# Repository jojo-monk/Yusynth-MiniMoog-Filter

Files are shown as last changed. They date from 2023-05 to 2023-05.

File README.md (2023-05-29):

# Yusynth-MiniMoog-Filter
Adaptation du Yusynth [MiniMoog Filter](http://yusynth.net/Modular/index_en.html) au format Eurorack

testé et fonctionnel.

petit défaut esthetique : sérigraphie un peu trop petite et trop proche des boutons.

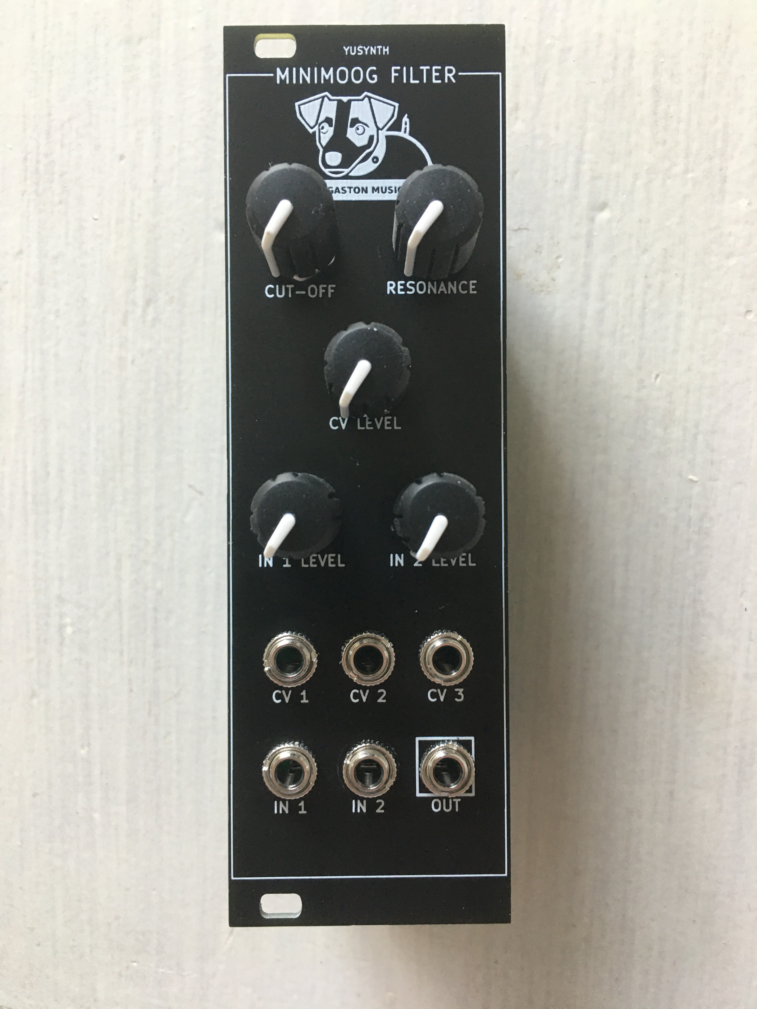
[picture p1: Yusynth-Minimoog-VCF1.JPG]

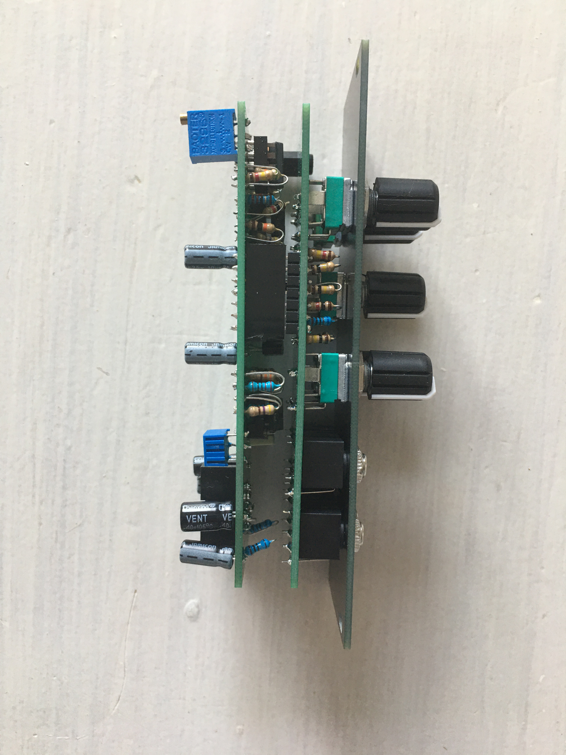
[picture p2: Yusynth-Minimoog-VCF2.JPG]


[Build document](https://htmlpreview.github.io/?https://github.com/jojo-monk/Yusynth-MiniMoog-Filter/blob/main/ibom.html)

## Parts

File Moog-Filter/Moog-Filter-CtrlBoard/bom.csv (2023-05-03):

Designator | Footprint | Quantity | Value | LCSC Part #
H1 | MountingHole_3.2mm_M3 | 1 | MountingHole
J3 | Jack_3.5mm_QingPu_WQP-PJ398SM_Vertical | 1 | IN1
J4 | Jack_3.5mm_QingPu_WQP-PJ398SM_Vertical | 1 | IN2
J5 | Jack_3.5mm_QingPu_WQP-PJ398SM_Vertical | 1 | CV1
J6 | Jack_3.5mm_QingPu_WQP-PJ398SM_Vertical | 1 | CV2
J7 | Jack_3.5mm_QingPu_WQP-PJ398SM_Vertical | 1 | CV3
J8 | PinHeader_1x07_P2.54mm_Vertical | 1 | Conn_01x07_Female
J9 | Jack_3.5mm_QingPu_WQP-PJ398SM_Vertical | 1 | OUT
R27 | R_Axial_DIN0207_L6.3mm_D2.5mm_P2.54mm_Vertical | 1 | 680
R28 | R_Axial_DIN0207_L6.3mm_D2.5mm_P2.54mm_Vertical | 1 | 150K
R29, R30, R32, R33 | R_Axial_DIN0207_L6.3mm_D2.5mm_P2.54mm_Vertical | 4 | 100K
R31 | R_Axial_DIN0207_L6.3mm_D2.5mm_P2.54mm_Vertical | 1 | 120K
R34 | R_Axial_DIN0207_L6.3mm_D2.5mm_P2.54mm_Vertical | 1 | 1K
RV4 | Potentiometer_Alpha_RD901F-40-00D_Single_Vertical | 1 | Freq 10K Lin
RV5, RV6 | Potentiometer_Alpha_RD901F-40-00D_Single_Vertical | 2 | INPUT LEVEL 50K Log
RV7 | Potentiometer_Alpha_RD901F-40-00D_Single_Vertical | 1 | Ctrl LEVEL 50K Lin
RV8 | Potentiometer_Alpha_RD901F-40-00D_Single_Vertical | 1 | Emphasis 50K antilog

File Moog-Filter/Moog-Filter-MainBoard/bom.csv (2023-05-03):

Designator | Footprint | Quantity | Value | LCSC Part #
C1 | C_Rect_L7.0mm_W3.5mm_P5.00mm | 1 | 100pF
C10, C11, C2 | CP_Radial_D5.0mm_P2.00mm | 3 | 10uF
C12 | C_Rect_L7.0mm_W3.5mm_P5.00mm | 1 | 100nF
C13, C14 | CP_Radial_D5.0mm_P2.00mm | 2 | 22uF
C3, C4, C5, C6 | C_Rect_L7.0mm_W3.5mm_P5.00mm | 4 | 47nF
C7 | CP_Radial_D8.0mm_P3.50mm | 1 | 220uF
C8, C9 | C_Rect_L7.0mm_W3.5mm_P5.00mm | 2 | 220nF
H2 | MountingHole_3.2mm_M3 | 1 | MountingHole
J1 | PinHeader_1x07_P2.54mm_Vertical | 1 | Conn_01x07_Male
J2 | Eurorack_power_header | 1 | EURO_PWR_2x5
Q1 | TO-92_HandSolder | 1 | BC557
Q2, Q3, Q4, Q5, Q6, Q7 | TO-92_HandSolder | 6 | BC547
R1, R23 | R_Axial_DIN0207_L6.3mm_D2.5mm_P2.54mm_Vertical | 2 | 56K
R10 | R_Axial_DIN0207_L6.3mm_D2.5mm_P2.54mm_Vertical | 1 | 100K
R11, R20, R21 | R_Axial_DIN0207_L6.3mm_D2.5mm_P2.54mm_Vertical | 3 | 1K
R12, R5, R6, R7 | R_Axial_DIN0207_L6.3mm_D2.5mm_P2.54mm_Vertical | 4 | 150
R13 | R_Axial_DIN0207_L6.3mm_D2.5mm_P2.54mm_Vertical | 1 | 220
R14, R4 | R_Axial_DIN0207_L6.3mm_D2.5mm_P2.54mm_Vertical | 2 | 330
R15, R16 | R_Axial_DIN0207_L6.3mm_D2.5mm_P2.54mm_Vertical | 2 | 47K
R17, R22 | R_Axial_DIN0207_L6.3mm_D2.5mm_P2.54mm_Vertical | 2 | 220K
R18 | R_Axial_DIN0207_L6.3mm_D2.5mm_P2.54mm_Vertical | 1 | 22
R19 | R_Axial_DIN0207_L6.3mm_D2.5mm_P2.54mm_Vertical | 1 | 180
R2 | R_Axial_DIN0207_L6.3mm_D2.5mm_P2.54mm_Vertical | 1 | 1.8K
R24 | R_Axial_DIN0207_L6.3mm_D2.5mm_P2.54mm_Vertical | 1 | 120K
R25, R26 | R_Axial_DIN0207_L6.3mm_D2.5mm_P2.54mm_Vertical | 2 | 10
R3 | R_Axial_DIN0207_L6.3mm_D2.5mm_P2.54mm_Vertical | 1 | 10K
R8, R9 | R_Axial_DIN0207_L6.3mm_D2.5mm_P2.54mm_Vertical | 2 | 470
RV1 | Potentiometer_Bourns_3296W_Vertical | 1 | 500
RV2 | Potentiometer_Bourns_3296W_Vertical | 1 | 10K
RV3 | Potentiometer_Bourns_3296W_Vertical | 1 | 1K
U1 | DIP-8_W7.62mm_LongPads | 1 | TL072
U2, U3 | DIP-14_W7.62mm_LongPads | 2 | CA3046

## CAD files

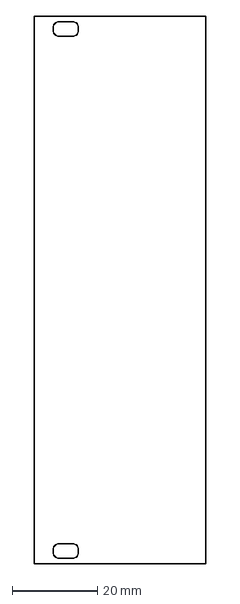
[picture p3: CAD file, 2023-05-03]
Moog-Filter/FrontPanel.dxf
40.3 x 128.4 mm

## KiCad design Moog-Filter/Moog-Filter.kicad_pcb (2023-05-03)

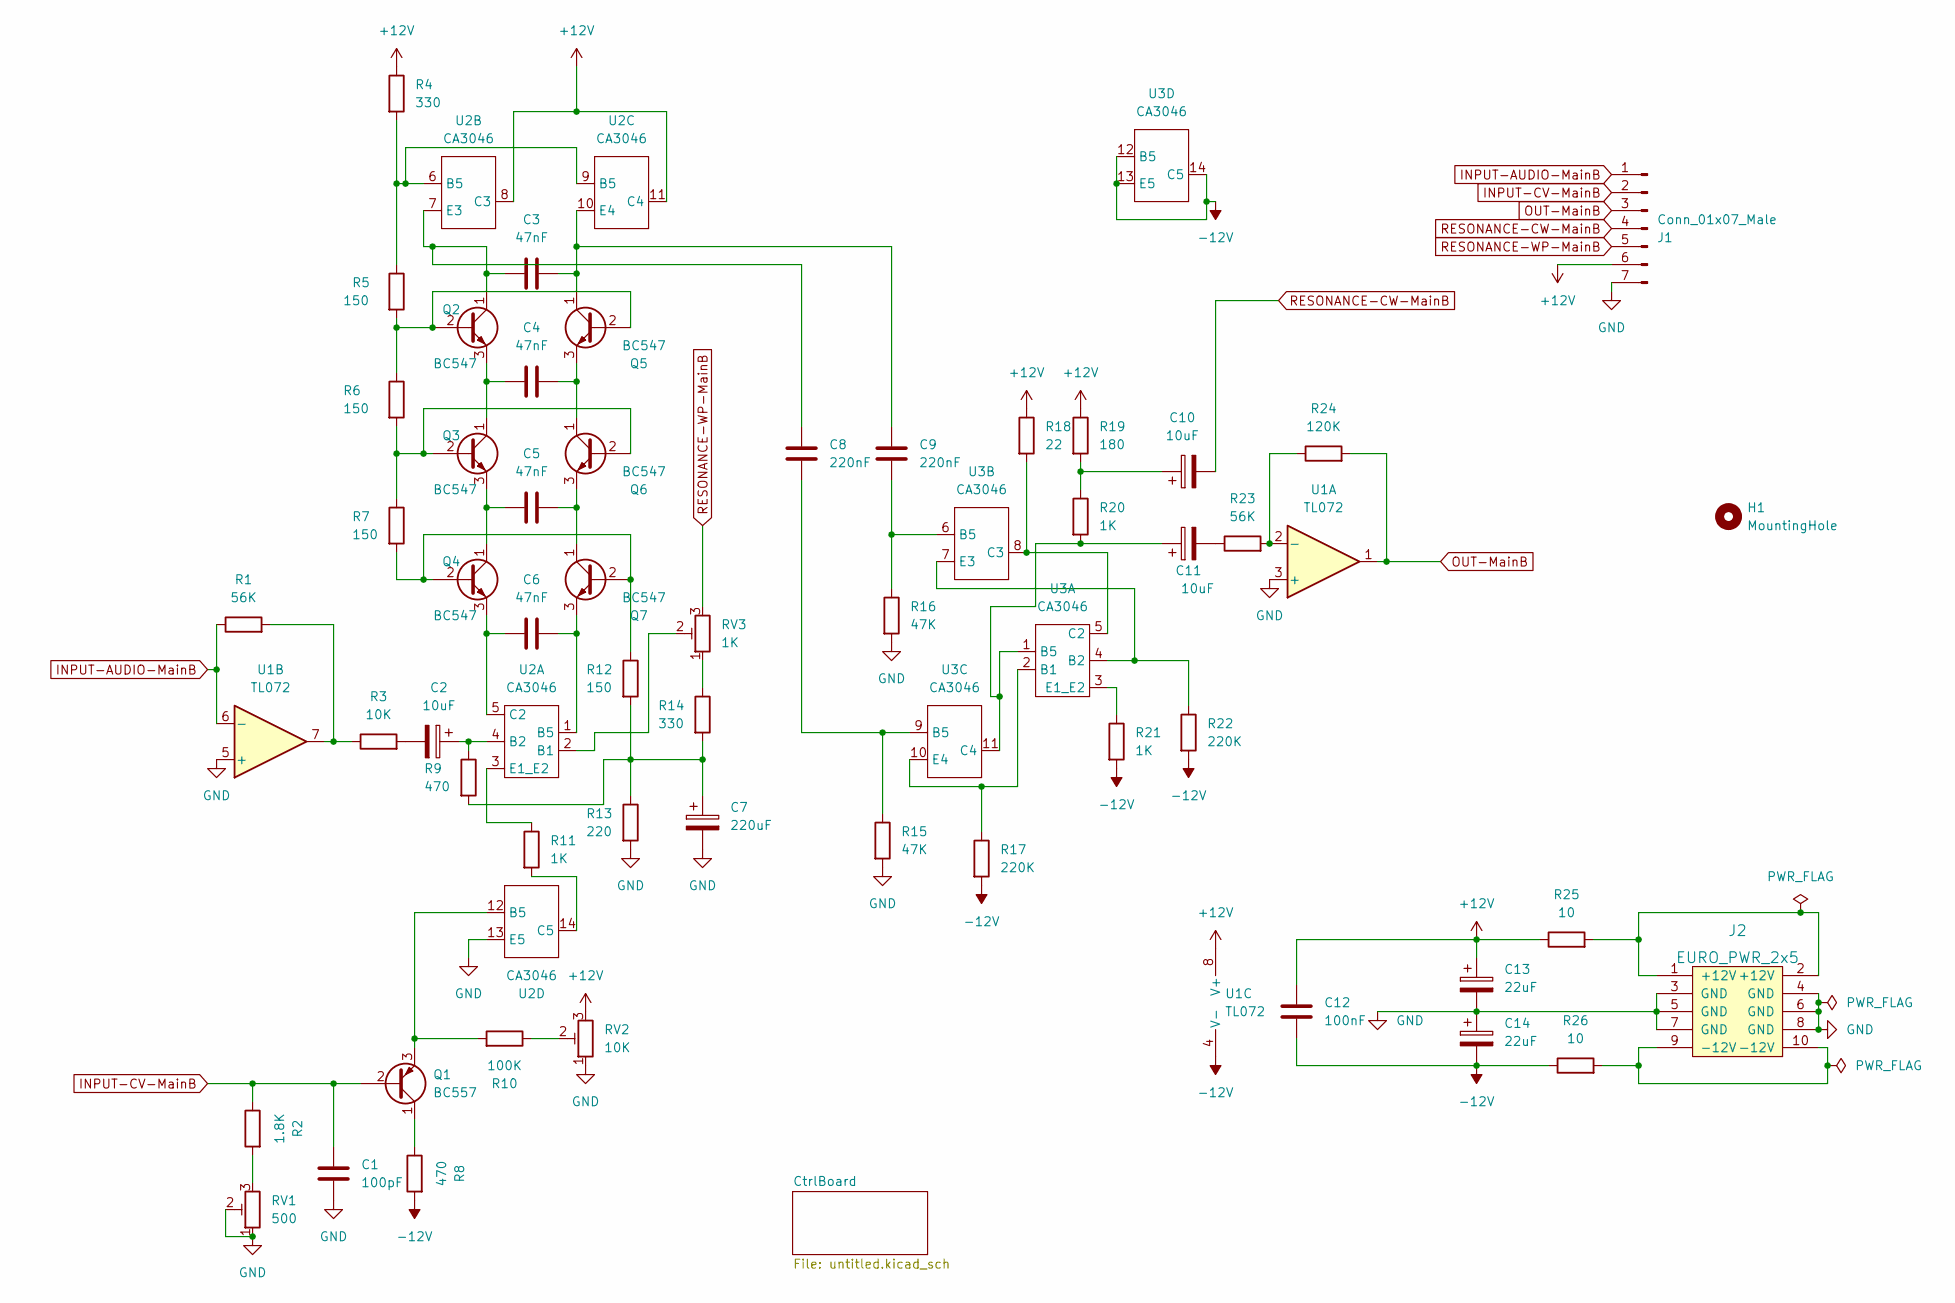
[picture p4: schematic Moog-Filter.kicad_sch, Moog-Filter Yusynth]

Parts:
C1: 100pF; C_Rect_L7.0mm_W3.5mm_P5.00mm
C2, C10, C11: 10uF; CP_Radial_D5.0mm_P2.00mm
C3, C4, C5, C6: 47nF; C_Rect_L7.0mm_W3.5mm_P5.00mm
C7: 220uF; CP_Radial_D8.0mm_P3.50mm
C8, C9: 220nF; C_Rect_L7.0mm_W3.5mm_P5.00mm
C12: 100nF; C_Rect_L7.0mm_W3.5mm_P5.00mm
C13, C14: 22uF; CP_Radial_D5.0mm_P2.00mm
H1: MountingHole; MountingHole_3.2mm_M3
J1: Conn_01x07_Male; PinHeader_1x07_P2.54mm_Vertical
J2: EURO_PWR_2x5; Eurorack_power_header
Q1: BC557; TO-92_HandSolder
Q2, Q3, Q4, Q5, Q6, Q7: BC547; TO-92_HandSolder
R1, R23: 56K; R_Axial_DIN0207_L6.3mm_D2.5mm_P2.54mm_Vertical
R2: 1.8K; R_Axial_DIN0207_L6.3mm_D2.5mm_P2.54mm_Vertical
R3: 10K; R_Axial_DIN0207_L6.3mm_D2.5mm_P2.54mm_Vertical
R4, R14: 330; R_Axial_DIN0207_L6.3mm_D2.5mm_P2.54mm_Vertical
R5, R6, R7, R12: 150; R_Axial_DIN0207_L6.3mm_D2.5mm_P2.54mm_Vertical
R8, R9: 470; R_Axial_DIN0207_L6.3mm_D2.5mm_P2.54mm_Vertical
R10: 100K; R_Axial_DIN0207_L6.3mm_D2.5mm_P2.54mm_Vertical
R11, R20, R21: 1K; R_Axial_DIN0207_L6.3mm_D2.5mm_P2.54mm_Vertical
R13: 220; R_Axial_DIN0207_L6.3mm_D2.5mm_P2.54mm_Vertical
R15, R16: 47K; R_Axial_DIN0207_L6.3mm_D2.5mm_P2.54mm_Vertical
R17, R22: 220K; R_Axial_DIN0207_L6.3mm_D2.5mm_P2.54mm_Vertical
R18: 22; R_Axial_DIN0207_L6.3mm_D2.5mm_P2.54mm_Vertical
R19: 180; R_Axial_DIN0207_L6.3mm_D2.5mm_P2.54mm_Vertical
R24: 120K; R_Axial_DIN0207_L6.3mm_D2.5mm_P2.54mm_Vertical
R25, R26: 10; R_Axial_DIN0207_L6.3mm_D2.5mm_P2.54mm_Vertical
RV1: 500; Potentiometer_Bourns_3296W_Vertical
RV2: 10K; Potentiometer_Bourns_3296W_Vertical
RV3: 1K; Potentiometer_Bourns_3296W_Vertical
U1: TL072; DIP-8_W7.62mm_LongPads
U2, U3: CA3046; DIP-14_W7.62mm_LongPads

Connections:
+12V: C12.1, C13.1, J1.6, R4.1, R18.1, R19.1, R25.1, RV2.3, U1.8 (V+), U2.8 (C3), U2.11 (C4); also elsewhere on the board
-12V: C12.2, C14.2, R8.2, R17.2, R21.2, R22.2, R26.1, U1.4 (V-), U3.12 (B5), U3.13 (E5), U3.14 (C5)
GND: C1.2, C7.2, C13.2, C14.1, J1.7, J2.3 (GND), J2.4 (GND), J2.5 (GND), J2.6 (GND), J2.7 (GND), J2.8 (GND), R13.2, R15.2, R16.2, RV1.1, RV1.2, RV2.1, U1.3 (+), U1.5 (+), U2.13 (E5); also elsewhere on the board
INPUT-AUDIO-MainB: J1.1, R1.1, U1.6 (-)
INPUT-CV-MainB: C1.1, J1.2, Q1.2 (B), R2.1
unnamed: C2.1, R9.1, U2.4 (B2)
unnamed: C2.2, R3.2
unnamed: C3.1, C8.1, Q2.1 (C), U2.7 (E3)
unnamed: C3.2, C9.1, Q5.1 (C), U2.10 (E4)
unnamed: C4.1, Q2.3 (E), Q3.1 (C)
unnamed: C4.2, Q5.3 (E), Q6.1 (C)
unnamed: C5.1, Q3.3 (E), Q4.1 (C)
unnamed: C5.2, Q6.3 (E), Q7.1 (C)
unnamed: C6.1, Q4.3 (E), U2.5 (C2)
unnamed: C6.2, Q7.3 (E), U2.1 (B5)
unnamed: C7.1, R9.2, R12.2, R13.1, R14.2
unnamed: C8.2, R15.1, U3.9 (B5)
unnamed: C9.2, R16.1, U3.6 (B5)
unnamed: C10.1, R19.2, R20.1
unnamed: C11.1, R20.2, U3.1 (B5), U3.11 (C4)
unnamed: C11.2, R23.1
unnamed: J2.1 (+12V), J2.2 (+12V), R25.2
unnamed: J2.9 (-12V), J2.10 (-12V), R26.2
unnamed: Q1.1 (C), R8.1
unnamed: Q1.3 (E), R10.2, U2.12 (B5)
unnamed: Q2.2 (B), Q5.2 (B), R5.2, R6.1
unnamed: Q3.2 (B), Q6.2 (B), R6.2, R7.1
unnamed: Q4.2 (B), Q7.2 (B), R7.2, R12.1
unnamed: R1.2, R3.1, U1.7
unnamed: R2.2, RV1.3
unnamed: R4.2, R5.1, U2.6 (B5), U2.9 (B5)
unnamed: R10.1, RV2.2
unnamed: R11.1, U2.3 (E1_E2)
unnamed: R11.2, U2.14 (C5)
unnamed: R14.1, RV3.1
unnamed: R17.1, U3.2 (B1), U3.10 (E4)
unnamed: R18.2, U3.5 (C2), U3.8 (C3)
unnamed: R21.1, U3.3 (E1_E2)
unnamed: R22.1, U3.4 (B2), U3.7 (E3)
unnamed: R23.2, R24.1, U1.2 (-)
unnamed: RV3.2, U2.2 (B1)
OUT-MainB: J1.3, R24.2, U1.1
RESONANCE-CW-MainB: C10.2, J1.4
RESONANCE-WP-MainB: J1.5, RV3.3

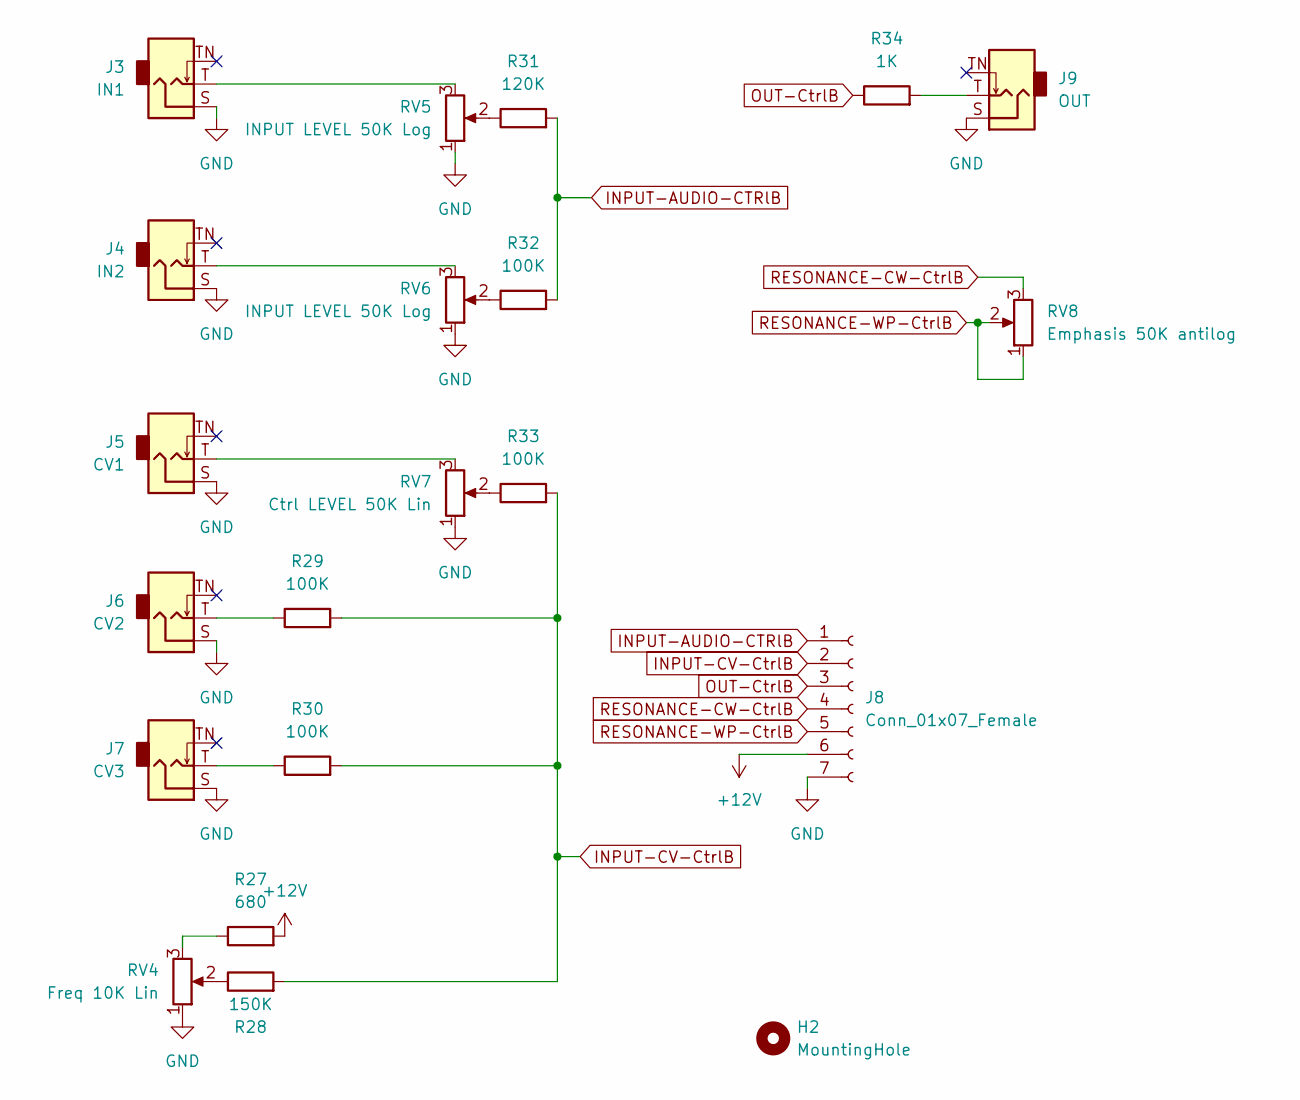
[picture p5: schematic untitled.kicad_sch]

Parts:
H2: MountingHole; MountingHole_3.2mm_M3
J3: IN1; Jack_3.5mm_QingPu_WQP-PJ398SM_Vertical
J4: IN2; Jack_3.5mm_QingPu_WQP-PJ398SM_Vertical
J5: CV1; Jack_3.5mm_QingPu_WQP-PJ398SM_Vertical
J6: CV2; Jack_3.5mm_QingPu_WQP-PJ398SM_Vertical
J7: CV3; Jack_3.5mm_QingPu_WQP-PJ398SM_Vertical
J8: Conn_01x07_Female; PinHeader_1x07_P2.54mm_Vertical
J9: OUT; Jack_3.5mm_QingPu_WQP-PJ398SM_Vertical
R27: 680; R_Axial_DIN0207_L6.3mm_D2.5mm_P2.54mm_Vertical
R28: 150K; R_Axial_DIN0207_L6.3mm_D2.5mm_P2.54mm_Vertical
R29, R30, R32, R33: 100K; R_Axial_DIN0207_L6.3mm_D2.5mm_P2.54mm_Vertical
R31: 120K; R_Axial_DIN0207_L6.3mm_D2.5mm_P2.54mm_Vertical
R34: 1K; R_Axial_DIN0207_L6.3mm_D2.5mm_P2.54mm_Vertical
RV4: Freq 10K Lin; Potentiometer_Alpha_RD901F-40-00D_Single_Vertical
RV5, RV6: INPUT LEVEL 50K Log; Potentiometer_Alpha_RD901F-40-00D_Single_Vertical
RV7: Ctrl LEVEL 50K Lin; Potentiometer_Alpha_RD901F-40-00D_Single_Vertical
RV8: Emphasis 50K antilog; Potentiometer_Alpha_RD901F-40-00D_Single_Vertical

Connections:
+12V: J8.6, R27.2; also elsewhere on the board
GND: J3.S, J4.S, J5.S, J6.S, J7.S, J8.7, J9.S, RV4.1, RV5.1, RV6.1, RV7.1; also elsewhere on the board
INPUT-AUDIO-CTRlB: J8.1, R31.2, R32.2
INPUT-CV-CtrlB: J8.2, R28.2, R29.2, R30.2, R33.2
unnamed: J3.T, RV5.3
unnamed: J4.T, RV6.3
unnamed: J5.T, RV7.3
unnamed: J6.T, R29.1
unnamed: J7.T, R30.1
unnamed: J9.T, R34.2
unnamed: R27.1, RV4.3
unnamed: R28.1, RV4.2
unnamed: R31.1, RV5.2
unnamed: R32.1, RV6.2
unnamed: R33.1, RV7.2
OUT-CtrlB: J8.3, R34.1
RESONANCE-CW-CtrlB: J8.4, RV8.3
RESONANCE-WP-CtrlB: J8.5, RV8.1, RV8.2

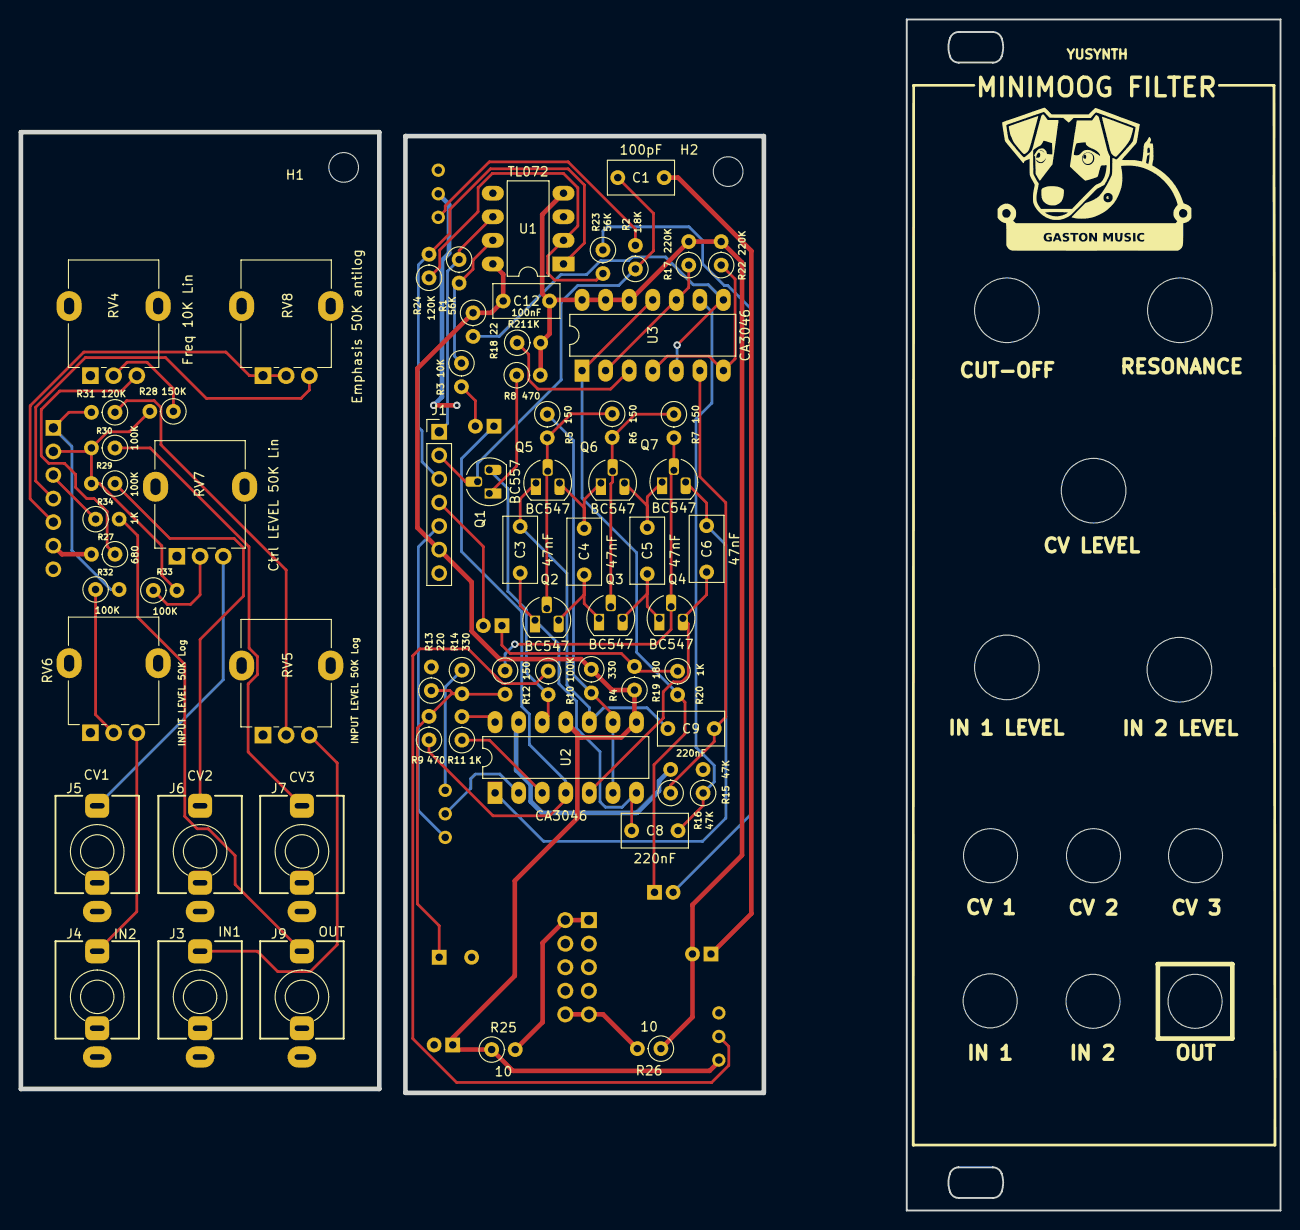
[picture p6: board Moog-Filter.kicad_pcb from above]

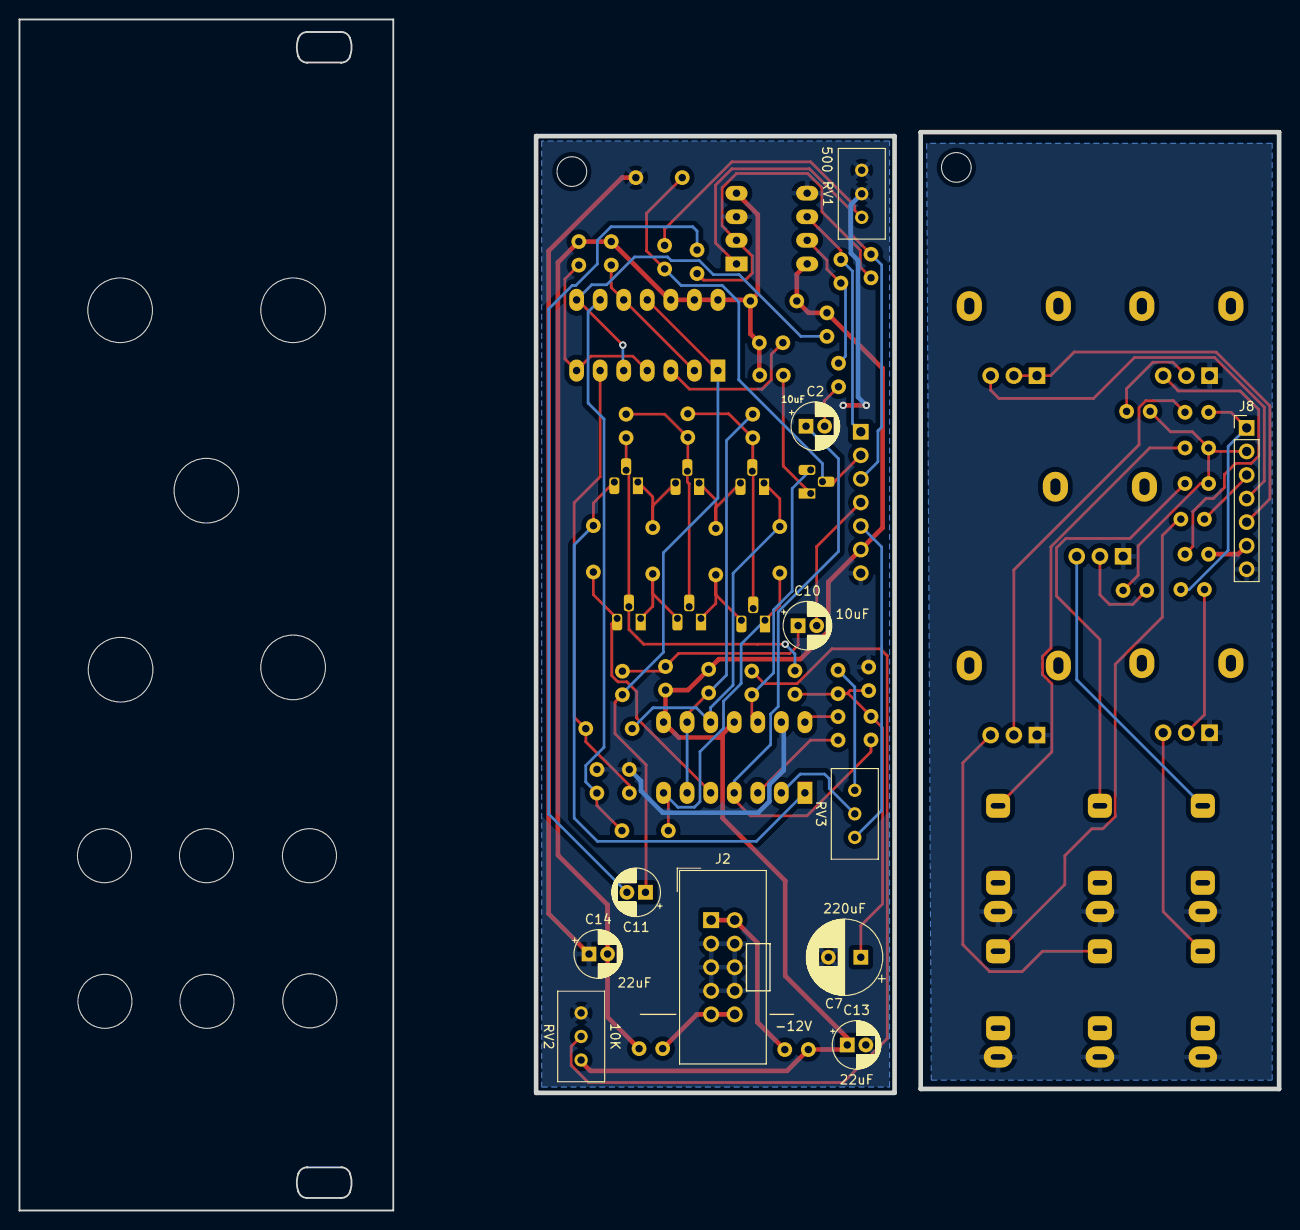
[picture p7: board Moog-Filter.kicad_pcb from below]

Board: 2 copper layers, 135.8 x 128.4 mm, 77 parts (11 on the bottom side), 60 nets.

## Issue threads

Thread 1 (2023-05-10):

Panel dimensions missing in gerber

CoogLFish, 2023-05-10:
I assume the size is standard Doepfer 8HP, which would be 40.3mm by 128.5mm. Correct me if I'm wrong?

jojo-monk, 2023-08-12:
yes, that's it

Closed 2023-08-12.
